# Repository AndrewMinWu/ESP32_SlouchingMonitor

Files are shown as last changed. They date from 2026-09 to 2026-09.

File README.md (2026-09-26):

# Laptop Slouching Monitor










## Repository Structure

```text
├── hardware/          # Schematic, PCB, and gerbers
├── firmware/          # PlatformIO C++ code, and Python script
└── docs/              # Datasheets
```

## Purpose & Motivation:
Spending long hours working at a computer, I noticed my posture deteriorating as I constantly leaned closer to the monitor. Over time, this habit leads to back pain and eye strain (probably why my eyesight is so bad). Therefore, to prevent future issues and to force myself to build better sitting habits, I designed a PCB using an ESP32 and a Time-of-Flight (ToF) sensor to accurately monitor my distance from the screen and trigger a desktop popup whenever I slouch.

## Design

### Component List (BOM)
1. ESP32-C3-WROOM-02 ([Datasheet](https://www.espressif.com/sites/default/files/documentation/esp32-c3-wroom-02_datasheet_en.pdf))
2. AP2112K-3.3 LDO Voltage Regulator ([Datasheet](https://www.diodes.com/assets/Datasheets/AP2112.pdf))
3. GCT USB4105-GF-A USB-C Receptacle 16P SMD RA ([Datasheet](https://gct.co/files/drawings/usb4105.pdf))
4. VL53L0X Time-of-Flight Distance Sensor ([Datasheet](https://www.st.com/resource/en/datasheet/vl53l0x.pdf))
5. Passives & Miscellaneous Hardware:
   - Capacitors (0805, Ceramic)
   - Resistors (0805)
   - Push Buttons

### PCB, Schematic, Finished Board
The Schematic and PCB were designed in KiCad.

Schematic

<table width="100%">
  <tr>
    <td width="50%">PCB Layout</td>
    <td width="50%">3D Render</td>

  </tr>
</table>

### Firmware & Software
* **Language & Framework:** C++ (Arduino IDE) and Python, done using VSCode with PlatformIO
* **I2C Configuration:** GPIO 0 (SDA), GPIO 1 (SCL)
* **Desktop Application:** Python script using pyserial and tkinter for the popup alerts

## Assembly & Demonstration

**Short Demo**  
<video src="https://github.com/user-attachments/assets/37af02e7-89a8-4d62-8e1a-ba28e2ae51d5" width="100%" controls></video>

* **Assembly:** Hand-soldered all parts and tested the board with a multimeter (checking continuity with the implemented testpoints) before flashing firmware.

## Active Development

* **Enclosure:** 3D printing a case to mount the PCB to the top of my monitor, using Fusion 360

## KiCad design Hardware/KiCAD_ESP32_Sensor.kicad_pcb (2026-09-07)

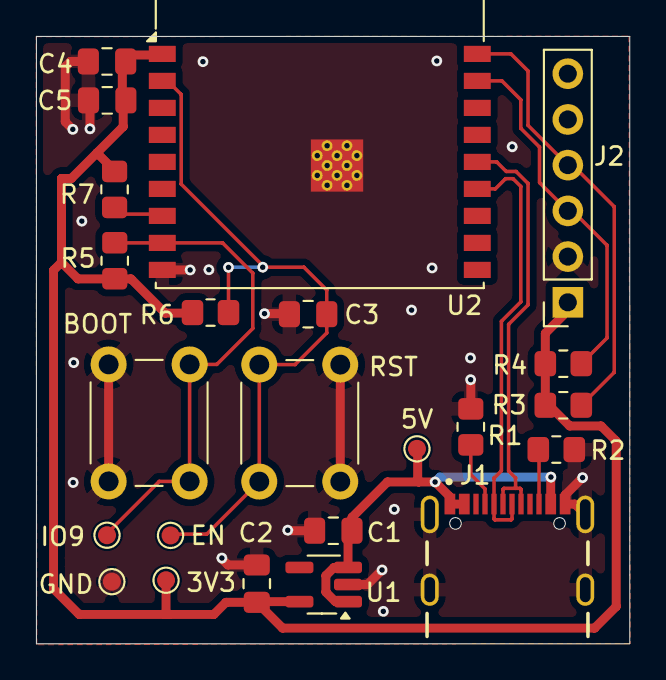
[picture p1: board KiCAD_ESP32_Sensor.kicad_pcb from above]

Board: 2 copper layers, 33.0 x 33.7 mm, 23 parts (0 on the bottom side), 12 nets.

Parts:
3V3: 3.3V; TestPoint_Pad_D1.0mm
5V: 5V; TestPoint_Pad_D1.0mm
BOOT: SW_Push; SW_PUSH_6mm_H5mm
C1, C2, C3: 1u; C_0805_2012Metric_Pad1.18x1.45mm_HandSolder
C4: 0.1u; C_0805_2012Metric_Pad1.18x1.45mm_HandSolder
C5: 10u; C_0805_2012Metric_Pad1.18x1.45mm_HandSolder
EN: EN; TestPoint_Pad_D1.0mm
GND: GND; TestPoint_Pad_D1.0mm
IO9: IO0; TestPoint_Pad_D1.0mm
J1: USB_C_Receptacle_USB2.0_16P; GCT_USB4105-GF-A
J2: VL53L0X_Module; PinSocket_1x06_P2.54mm_Vertical
R1, R2: 5.1k; R_0805_2012Metric_Pad1.20x1.40mm_HandSolder
R3, R4: 4.7k; R_0805_2012Metric_Pad1.20x1.40mm_HandSolder
R5, R6, R7: 10k; R_0805_2012Metric_Pad1.20x1.40mm_HandSolder
RST: SW_Push; SW_PUSH_6mm_H5mm
U1: AP2112K-3.3; SOT-23-5_HandSoldering
U2: ESP32-C3-WROOM-02

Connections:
+3.3V: 3V3.1 (1_1), C2.1, C4.1, C5.1, J2.1, R3.2, R4.2, R5.1, R6.1, R7.1, U1.5 (VOUT), U2.1 (3V3)
+5V: 5V.1 (1_1), C1.1, J1.A1_B12 (VBUS_B9), J1.A4_B9 (VBUS_B4), J1.B4_A9 (VBUS_A4), U1.1 (VIN), U1.3 (EN)
D+: J1.A6 (D+_A6), J1.B6 (D+_B6), U2.14 (IO19)
D-: J1.A7 (D-_A7), J1.B7 (D-_B7), U2.13 (IO18)
EN: C3.2, EN.1 (1_1), R6.2, RST.1, U2.2 (EN)
GND: BOOT.2, C1.2, C2.2, C3.1, C4.2, C5.2, GND.1 (1_1), J1.B1_A12 (GND_A12), J1.SH1 (SHIELD_SH), J1.SH2 (SHIELD_SH), J1.SH3 (SHIELD_SH), J1.SH4 (SHIELD_SH), J2.2, R1.1, R2.1, RST.2, U1.2 (GND), U2.9 (GND), U2.19 (GND)
IO9: BOOT.1, IO9.1 (1_1), R5.2, U2.8 (IO9)
unnamed: J1.A5 (CC1_A5), R1.2
unnamed: J1.B5 (CC2_B5), R2.2
unnamed: R7.2, U2.7 (IO8)
SCL: J2.3, R4.1, U2.17 (IO1)
SDA: J2.4, R3.1, U2.18 (IO0)

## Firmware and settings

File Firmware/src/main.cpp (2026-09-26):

#include <Arduino.h>
#include <Wire.h>
#include "Adafruit_VL53L0X.h"

Adafruit_VL53L0X lox = Adafruit_VL53L0X();

void setup() {
    Serial.begin(115200);
    
    // Initializing i2c pins
    Wire.begin(0, 1); 

    // Halt execution on sensor if initialization fails
    if (!lox.begin()) {
        while (1); 
    }
}

void loop() {
    VL53L0X_RangingMeasurementData_t measure;
    
    // Sensor measurement
    lox.rangingTest(&measure, false); 

    // Status 4 indicates out of range; filter valid data
    if (measure.RangeStatus != 4) { 
        Serial.print("Distance: ");
        Serial.print(measure.RangeMilliMeter);
        Serial.println(" mm");
    }
    
    delay(500); 
}

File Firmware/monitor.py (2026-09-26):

import serial
import time
import tkinter as tk
from tkinter import messagebox

# Hide main root window
root = tk.Tk()
root.withdraw()

COM_PORT = 'COM3'
BAUD_RATE = 115200
DISTANCE_LIMIT = 375 
TIME_LIMIT = 5       

# Initialize serial connection
while True:
    try:
        ser = serial.Serial(COM_PORT, BAUD_RATE, timeout=1)
        break
    except Exception:
        time.sleep(1)

slouch_start = None

# Main data processing loop
while True:
    try:
        if ser.in_waiting > 0:
            line = ser.readline().decode('utf-8', errors='ignore').strip()
            
            if "Distance:" in line:
                try:
                    # Extract integer distance value from string
                    distance = int(line.split()[1])
                except (IndexError, ValueError):
                    continue

                # Filter invalid sensor spikes
                if distance > 2000:
                    continue

                # Check posture threshold
                if distance < DISTANCE_LIMIT:
                    
                    # Initialize timestamp on first detection
                    if slouch_start is None:
                        slouch_start = time.time()  
                    
                    # Display warning upon exceeding time limit
                    elif time.time() - slouch_start >= TIME_LIMIT:
                        root.attributes('-topmost', True)
                        messagebox.showwarning("Posture Alert", "Distance threshold exceeded.")
                        slouch_start = None  
                
                else:
                    # Clear timestamp on proper posture
                    slouch_start = None  

    except Exception:
        # Reset state on connection drop
        slouch_start = None
        time.sleep(1)

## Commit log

2026-09-06 Finalized: components & pcb purchased
    [KiCAD_ESP32_Sensor-B_Cu.gbl, KiCAD_ESP32_Sensor-B_Mask.gbs, KiCAD_ESP32_Sensor-B_Paste.gbp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]
2026-09-07 Pushed to production
    [KiCAD_ESP32_Sensor-B_Cu.gbl, KiCAD_ESP32_Sensor-B_Mask.gbs, KiCAD_ESP32_Sensor-B_Paste.gbp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]
2026-09-18 C++ Code using Arduino IDE
2026-09-18 Updated the folder structure for this project; everything has better organization now
    [KiCAD_ESP32_Sensor-B_Cu.gbl, KiCAD_ESP32_Sensor-B_Mask.gbs, KiCAD_ESP32_Sensor-B_Paste.gbp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]
2026-09-18 Finalized file organization
    [KiCAD_ESP32_Sensor.kicad_pcb, KiCAD_ESP32_Sensor.kicad_sch]
2026-09-20 FInalized code, shortened cpp file
    [main.cpp, monitor.py]
2026-09-20 Finalized project files
    [KiCAD_ESP32_Sensor.kicad_sch]
2026-09-20 Update section title for PCB and Schematic
2026-09-20 Finalized file structure
    [KiCAD_ESP32_Sensor.kicad_pcb, KiCAD_ESP32_Sensor.kicad_sch]
2026-09-21 Clarify assembly testing procedure in README
